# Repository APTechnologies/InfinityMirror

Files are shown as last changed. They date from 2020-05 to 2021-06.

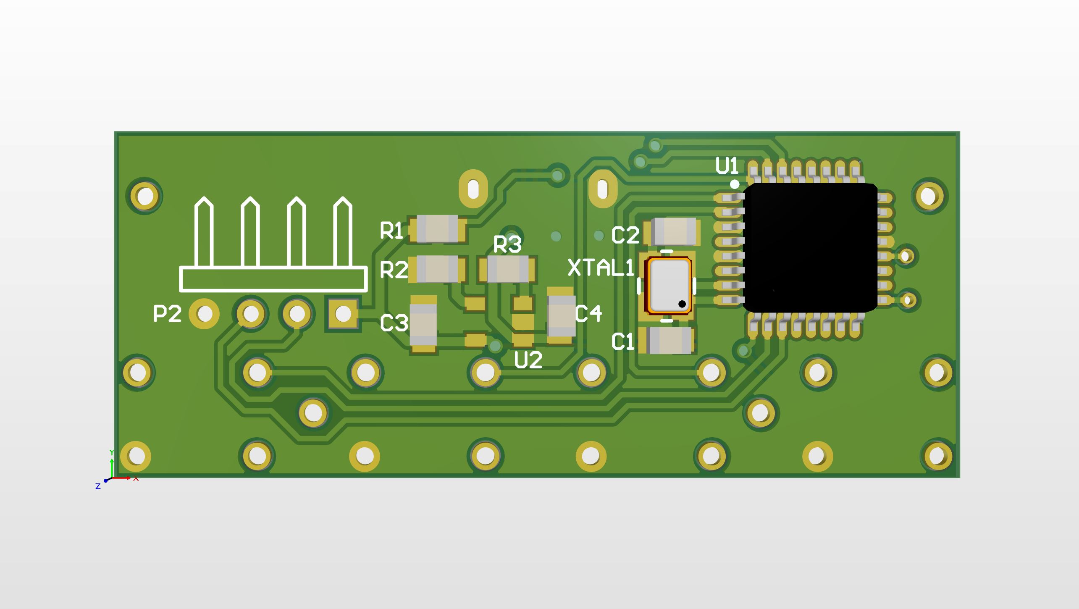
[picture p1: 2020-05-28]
PCB.JPG

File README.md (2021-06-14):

# InfinityMirror
All the files for building you own sleek RGB Infinity Mirror with complete control over the colors, animations and brightness. Hang it on your wall and enjoy!









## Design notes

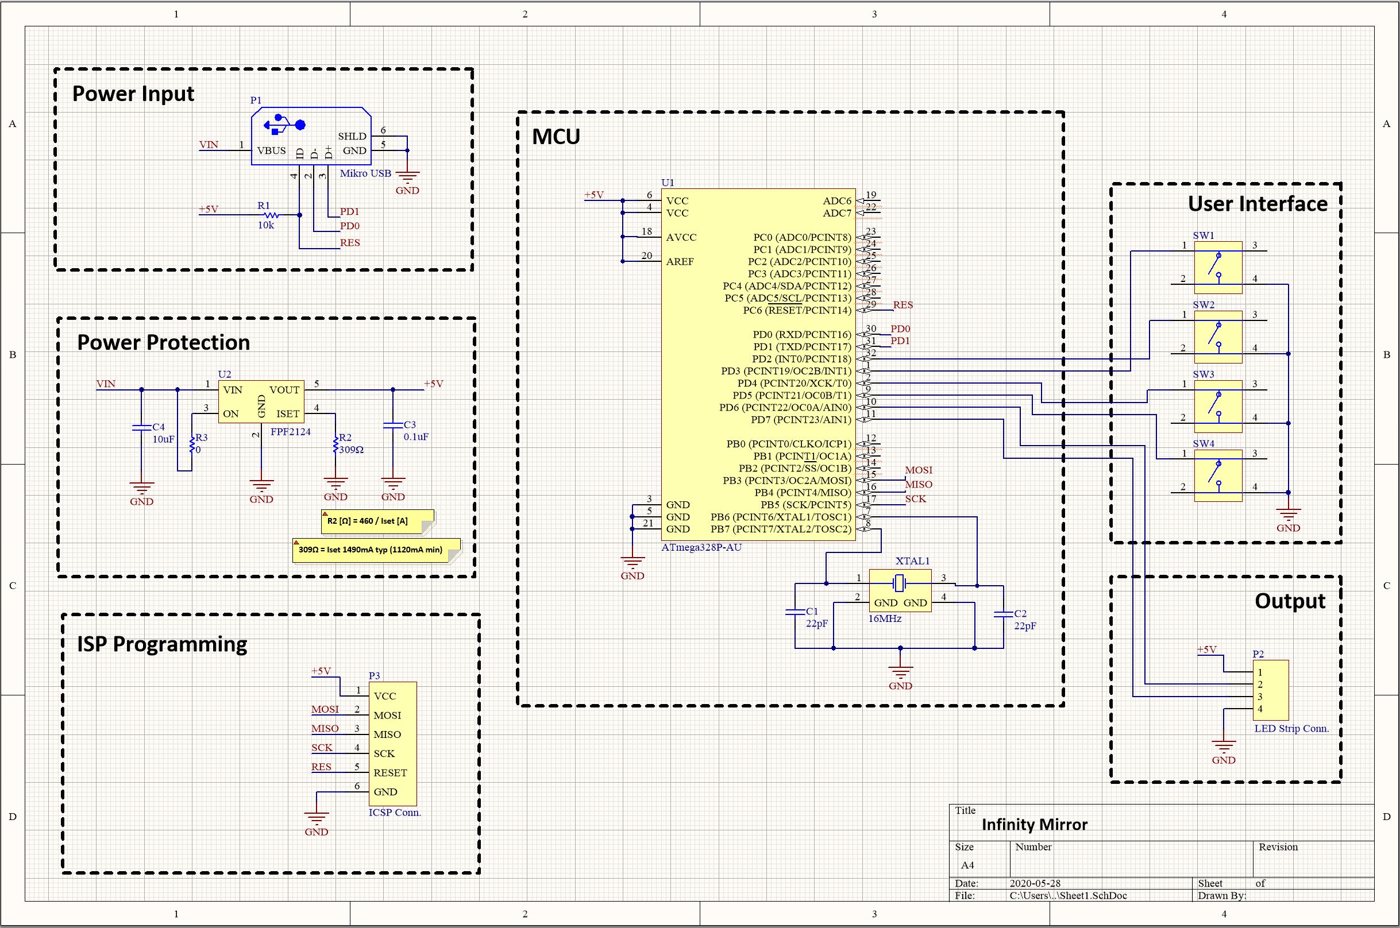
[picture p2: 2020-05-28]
Schematic.JPG

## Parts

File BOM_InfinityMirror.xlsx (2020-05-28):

 | BOM & COG
 | Project name: | Infinity Mirror
 | Version:
 | Created by: | ApTechnologies
 | Report date:
# | Part Name | Description | Comment | Cost (excl. 25% Tax) [SEK] | Cost (incl. 25% Tax) [SEK] | Quantity | In Stock | Total Cost (incl. 25% Tax) [SEK] | Footprint | Manufacturer | Manufacturer Part Numb. | Distributor | Distributor Part Numb.
1 | Cap. 22pF | ±5%, 50V, C0G, NP0, SMD |  | 1.01 | 1.26 | 2 | 18 | 2.525 | 0805 | KEMET | C0805C220J5GACTU | Digikey | 399-1113-1-ND
2 | Cap. 0.1uF | ±20%, 50V, X7R |  | 1.01 | 1.26 | 1 | 0 | 1.2625 | 0805 | Samsung Electro-Mechanics | CL21B104MBCNNNC | Digikey | 1276-2450-1-ND
3 | Cap. 10uF | ±10%, 16V, X5R, SMD |  | 1.21 | 1.51 | 1 | 0 | 1.5125 | 0805 | Samsung Electro-Mechanics | CL21A106KOQNNNG | Digikey | 1276-6455-1-ND
4 | Mikro USB, Vertical | MICRO B SKT, SMT, 30" |  | 8.44 | 10.55 | 1 | 9 | 10.55 | Custom | GCT | USB3140-30-0230-1-C | Digikey | 2073-USB3140-30-0230-1-CCT-ND
5 | Female Connector | 4pos, 2.5mm, THT |  | 2.81 | 3.51 | 1 | 9 | 3.5125 | 2x2.5mm Pads | Molex | 22057045 | Digikey | 23-0022057045-ND
6 | Male Connector | '4pos, 2.5mm, THT |  | 1.81 | 2.26 | 1 | 9 | 2.2625 | 2x2.5mm Pads | Molex | 50375043 | Digikey | WM17405-ND
7 | Crimp Terminal | 22-28AWG Crimp Tin |  | 1.01 | 1.26 | 4 | 34 | 5.05 | N/A | Molex | 39000160 | Digikey | WM9661CT-ND
8 | Res. 0 | 1/8W, SMD |  | 1.01 | 1.26 | 1 | 0 | 1.2625 | 0805 | Vishay Dale | CRCW08050000Z0EA | Digikey | 541-0.0ACT-ND
9 | Res. 309 | ±1%, 0.125W, 1/8W |  | 1.01 | 1.26 | 1 | 0 | 1.2625 | 0805 | Vishay Dale | CRCW0805309RFKEA | Digikey | 541-309CCT-ND
10 | Res. 10k | 1%, 1/8W, SMD |  | 1.01 | 1.26 | 1 | 9 | 1.2625 | 0805 | Vishay Dale | CRCW080510K0FKEA | Digikey | 541-10.0KCCT-ND
11 | Pushbutton | SPST-NO, 0.05A, 24V, THT |  | 1.31 | 1.64 | 4 | 46 | 6.55 | Custom | TE Connectivity ALCOSWITCH Switches | 3-1825910-5 | Digikey | 450-1644-ND
12 | FPF2124 | P-Ch Power Protection, 1.5A |  | 11.66 | 14.57 | 1 | 0 | 14.575 | SOT-23-5 | ON Semiconductor | FPF2124 | Digikey | FPF2124CT-ND
13 | ATmega328P-AU | AVR ATmega 8-bit MCU 20MHz 32KB (16K x 16) FLASH, THT |  | 20.9 | 26.12 | 1 | 9 | 26.125 | 32-TQFP | Microchip Technology | ATMEGA328P-AUR | Digikey | ATMEGA328P-AURCT-ND
14 | 4-Pin Crystal | 16MHz, 12pF, SMD |  | 5.63 | 7.04 | 1 | 8 | 7.0375 | 3,20mm x 2,50mm | ECS Inc. | ECS-160-12-33-AGN-TR | Digikey | XC2930CT-ND
15 | LED-Strip | WS2812b, Black, 46LEDs |  | N/A | 10.00 | 1 | 4 | 10 | N/A | Unknown | Unknown | Ebay | Unknown
16 | Power Adapter | 5,1V/2,5A microUSB |  | N/A | 99.00 | 1 | 1 | 99 | N/A | Raspberry Pi | 177-0223 | Inet | 2214339
17 | Hobby Mirror | 50cm x 50cm x 1mm |  | N/A | 104.00 | 1 | 3 | 104 | N/A | Unknown | Unknown | Slöjd-Detaljer | 1739-0000
18 | Acrylic | Clear, 50cm x 50cm x 2mm |  | N/A | 70.00 | 1 | 3 | 70 | N/A | Unknown | Unknown | Bauhaus | 4330093V
19 | Reflective Film | Silver 15% Film, 50cm x 50cm |  | N/A | 57.00 | 1 | 10 | 57 | N/A | AllStars | Unknown | Ebay | Unknown
20 | 3D-printed parts | ~150g PLA filament |  | N/A | 36.00 | 1 | N/A | 36 | N/A | N/A | N/A | N/A | N/A
21
22

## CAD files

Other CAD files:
Model_Bracket.f3d
Model_Butto_Holder.f3d
Model_LowerSegment.f3d
Model_Segment.f3d

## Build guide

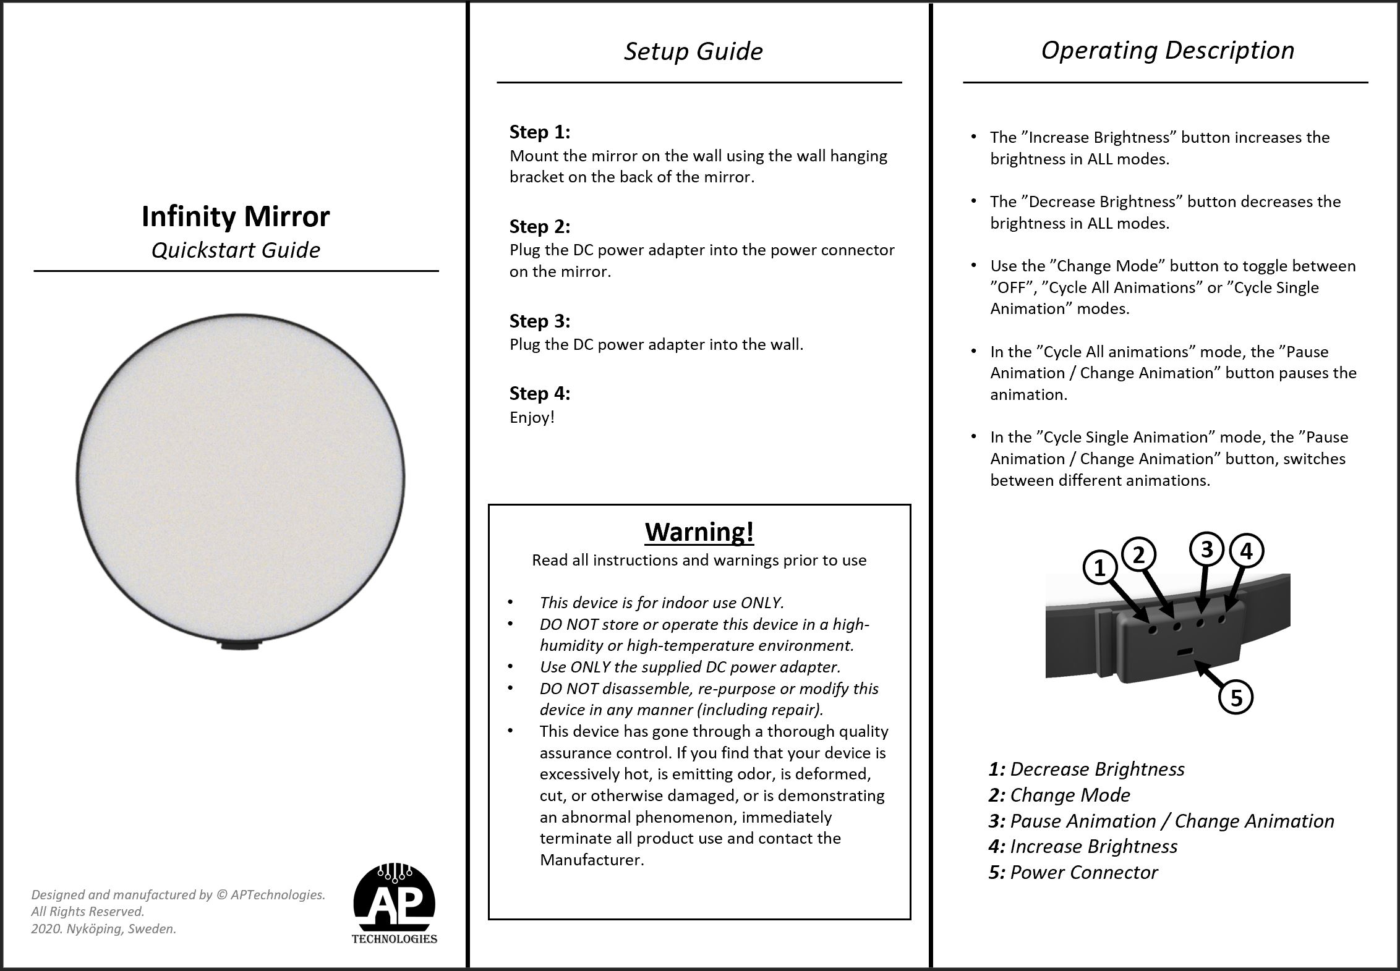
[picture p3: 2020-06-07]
Quickstart_Guide.JPG

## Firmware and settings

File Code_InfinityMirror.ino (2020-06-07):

/*
 * Code for controlling the LED-Stip in a Infinity Mirror using four buttons. 
 * Toggle between colors/animations, pause/unpause animations and change brightness.
 * Based on a Atmega328P-AU MCU
 * 
 * ##########################################################################################################
  Pin Configuration:

  D3 = Left Button   ( Input Pullup )
  D2 = Mode Button   ( Input Pullup )
  D4 = Config Button ( Input Pullup )
  D5 = Right Button  ( Input Pullup ) 
  D6 = Data Pin 
  ( D7 = Clock Pin )

  ###########################################################################################################

  Configuration for LED-Strip without CLK:

  - // #define CLK_PIN   7
  - // FastLED.addLeds<LED_TYPE, DATA_PIN, CLK_PIN, COLOR_ORDER>(leds, NUM_LEDS).setCorrection(TypicalLEDStrip);
  -    FastLED.addLeds<LED_TYPE,DATA_PIN,COLOR_ORDER>(leds, NUM_LEDS).setCorrection(TypicalLEDStrip);

  - pinMode(7, INPUT_PULLUP);


  Configuration for LED-Strip with CLK:
  
  - #define CLK_PIN   7
  - FastLED.addLeds<LED_TYPE, DATA_PIN, CLK_PIN, COLOR_ORDER>(leds, NUM_LEDS).setCorrection(TypicalLEDStrip);
  - // FastLED.addLeds<LED_TYPE,DATA_PIN,COLOR_ORDER>(leds, NUM_LEDS).setCorrection(TypicalLEDStrip);

  - // pinMode(7, INPUT_PULLUP);

  ###########################################################################################################

  Button Description:

    OFF Mode:  
              - Left Button   => Wake up to Cycle Animation Mode
              - Mode Button   => Wake up to Cycle Animation Mode
              - Config Button => Wake up to Cycle Animation Mode
              - Right Button  => Wake up to Cycle Animation Mode

    Cycle Animation Mode:  
              - Left Button   => Decrease Brightness
              - Mode Button   => Constant Animation Mode
              - Config Button => Pause Animation Mode
              - Right Button  => Increase Brightness

    Constant Animation Mode:   
              - Left Button   => Decrease Brightness
              - Mode Button   => OFF Mode
              - Config Button => Next Animation
              - Right Button  => Increase Brightness

    Pause Animation Mode:    
              - Left Button   => Decrease Brightness
              - Mode Button   => Cycle Animation Mode
              - Config Button => Unpause Animation
              - Right Button  => Increase Brightness
*/


#include <FastLED.h>

FASTLED_USING_NAMESPACE

#define FRAMES_PER_SECOND  30
#define LED_TYPE    WS2812  // Type of LED in LED-Strip
#define COLOR_ORDER GRB
#define NUM_LEDS    46  // Number of LED:s in LED-Strip
#define DATA_PIN    6
//#define CLK_PIN   7

CRGB leds[NUM_LEDS];

const int bUpButton = 5; // Increase brightness
const int modeButton = 3; // Change Mode
const int configButton = 4; // Switch Animation
const int bDownButton = 2;  // Decrease Brightness

// Start Brightness
int BRIGHTNESS = 105;

void setup() {
  delay(1000); // delay for recovery

  FastLED.addLeds<LED_TYPE,DATA_PIN,COLOR_ORDER>(leds, NUM_LEDS).setCorrection(TypicalLEDStrip);
  //FastLED.addLeds<LED_TYPE, DATA_PIN, CLK_PIN, COLOR_ORDER>(leds, NUM_LEDS).setCorrection(TypicalLEDStrip);

  FastLED.setBrightness(BRIGHTNESS);

  // Used pins configuration
  pinMode(bUpButton, INPUT_PULLUP);
  pinMode(bDownButton, INPUT_PULLUP);
  pinMode(modeButton, INPUT_PULLUP);
  pinMode(configButton, INPUT_PULLUP);

  // Unused pins pulled high
  pinMode(0, INPUT_PULLUP);
  pinMode(1, INPUT_PULLUP);
  pinMode(7, INPUT_PULLUP);
  pinMode(8, INPUT_PULLUP);
  pinMode(9, INPUT_PULLUP);
  pinMode(10, INPUT_PULLUP);
  pinMode(11, INPUT_PULLUP);
  pinMode(12, INPUT_PULLUP);
  pinMode(13, INPUT_PULLUP);
  pinMode(A0, INPUT_PULLUP);
  pinMode(A1, INPUT_PULLUP);
  pinMode(A2, INPUT_PULLUP);
  pinMode(A3, INPUT_PULLUP);
  pinMode(A4, INPUT_PULLUP);
  pinMode(A5, INPUT_PULLUP);
}

#define ARRAY_SIZE(A) (sizeof(A) / sizeof((A)[0]))
// List of patterns to cycle through.  Each is defined as a separate function below.
typedef void (*SimplePatternList[])();
SimplePatternList gPatterns = { Rainbow, Confetti, Sinelon, Juggle, Bpm };

uint8_t gCurrentPatternNumber = 0; // Index number of which pattern is current
uint8_t gHue = 0; // rotating "base color" used by many of the patterns

// Cycle Animation Mode
void loop() {
  BrightnessAdjust();

  if (ButtonPress(modeButton) == true) {
    ConstantAnimation();
  }

  if (ButtonPress(configButton) == true) {
    PauseAnimation();
  }
  UpdateAnimation();
  NextAnimation();
}

bool ButtonPress(int button) {
  if (digitalRead(button) == LOW) {
    while (digitalRead(button) == LOW) {
      // Wait for button release 
    }
    return true;
  }
  return false;
}

void UpdateAnimation() {
  // Call the current pattern function once, updating the 'leds' array
  gPatterns[gCurrentPatternNumber]();

  // send the 'leds' array out to the actual LED strip
  FastLED.show();
  // insert a delay to keep the framerate modest
  FastLED.delay(1000 / FRAMES_PER_SECOND);

  // do some periodic updates
  EVERY_N_MILLISECONDS( 20 ) {
    gHue++;  // slowly cycle the "base color" through the rainbow
  }
  return;
}

void NextAnimation() {
  EVERY_N_SECONDS( 10 ) {
    NextPattern();  // change patterns periodically
  }
  return;
}

void PauseAnimation() {
  while (ButtonPress(configButton) == false) {
    BrightnessAdjust();

    if (ButtonPress(modeButton) == true) {
      Off();
      return;
    }
  }
  return;
}

void ConstantAnimation() {
  NextPattern(); // Go to next pattern to indicate mode change
  while(ButtonPress(modeButton) == false) {
    UpdateAnimation();
    BrightnessAdjust();

    if (ButtonPress(configButton) == true) {
      NextPattern();
    }
  }
  Off();
  return;
}

// Turn OFF all LEDs
void Off() {
  FastLED.setBrightness(0);
  FastLED.show();
  
  while (ButtonPress(modeButton) == false && ButtonPress(configButton) == false && ButtonPress(bUpButton) == false && ButtonPress(bDownButton) == false) {
    // Wait for a button press
  }
  FastLED.setBrightness(BRIGHTNESS);
  FastLED.show();
  return;
}

// Chnage brightness
void BrightnessAdjust() {

  if (ButtonPress(bUpButton) == true) {

    if (BRIGHTNESS > 245) {
      BRIGHTNESS = 245;
      BrightnessLimit();
    } else {
      BRIGHTNESS += 25;
    }
    
    FastLED.setBrightness(BRIGHTNESS);
    FastLED.show();
  }

  if (ButtonPress(bDownButton) == true) {

    BRIGHTNESS -= 25;

    if (BRIGHTNESS <= 5) {
      BRIGHTNESS = 5;
      BrightnessLimit();
    }
    FastLED.setBrightness(BRIGHTNESS);
    FastLED.show();
  }
  return;
}
// Show when MAX/MIN brightness is reached
void BrightnessLimit() {
  FastLED.setBrightness(0);
  FastLED.show();
  delay(80);
  FastLED.setBrightness(BRIGHTNESS);
  FastLED.show();
  return;
}

void NextPattern() {
  // add one to the current pattern number, and wrap around at the end
  gCurrentPatternNumber = (gCurrentPatternNumber + 1) % ARRAY_SIZE( gPatterns);
  return;
}

// Rainbow animation
void Rainbow() {
  // FastLED's built-in rainbow generator
  fill_rainbow( leds, NUM_LEDS, gHue, 7);
  return;
}

// Confetti animation
void Confetti() {
  // random colored speckles that blink in and fade smoothly
  fadeToBlackBy( leds, NUM_LEDS, 10);
  int pos = random16(NUM_LEDS);
  leds[pos] += CHSV( gHue + random8(64), 200, 255);
  return;
}

// Sinelon animation
void Sinelon() {
  // a colored dot sweeping back and forth, with fading trails
  fadeToBlackBy( leds, NUM_LEDS, 20);
  int pos = beatsin16( 13, 0, NUM_LEDS - 1 );
  leds[pos] += CHSV( gHue, 255, 192);
  return;
}

// Juggle animation
void Juggle() {
  // eight colored dots, weaving in and out of sync with each other
  fadeToBlackBy( leds, NUM_LEDS, 20);
  byte dothue = 0;
  for ( int i = 0; i < 8; i++) {
    leds[beatsin16( i + 7, 0, NUM_LEDS - 1 )] |= CHSV(dothue, 200, 255);
    dothue += 32;
  }
  return;
}

// BPM animation
void Bpm() {
  // colored stripes pulsing at a defined Beats-Per-Minute (BPM)
  uint8_t BeatsPerMinute = 62;
  CRGBPalette16 palette = PartyColors_p;
  uint8_t beat = beatsin8( BeatsPerMinute, 64, 255);
  for ( int i = 0; i < NUM_LEDS; i++) { //9948
    leds[i] = ColorFromPalette(palette, gHue + (i * 2), beat - gHue + (i * 10));
  }
  return;
} 
